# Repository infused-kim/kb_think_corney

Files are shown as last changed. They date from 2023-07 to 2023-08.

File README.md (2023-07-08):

# ThinkCorney

A wireless corne / crkbd ergonomic keyboard clone with support for a trackpoint. Built with ergogen v4.

> **Warning**
>
> This keyboard is still under development and not ready for manufacturing.

## Credits & Acknowledgements

- [Foostan's corne / crkbd](https://github.com/foostan/crkbd) for making the most popular ergo keyboard that is being used as the basis for this design
- Crehmann's [buzzard](https://github.com/crehmann/Buzzard) and [TPS42](https://github.com/crehmann/TPS42) for pioneering keyboards with trackpoints
- [Jon808517](https://reddit.com/r/ErgoMechKeyboards/comments/11ozztx/choc_spaced_corne_xiao/) for pointing me to the molex pico ezmate connector and joycon batteries
- And of course MrZealot for creating [ergogen](https://github.com/ergogen/ergogen)
- ceoloide for his awesome and creative ergogen tricks in [corney_island](https://github.com/ceoloide/corney-island/)

## License

**TLDR:**

- Personal use with attribution
- Commercial use not allowed

This work is licensed under a
[Creative Commons Attribution-ShareAlike 4.0 International License][cc-by-sa].

[][cc-by-sa]

[cc-by-sa]: http://creativecommons.org/licenses/by-sa/4.0/
[cc-by-sa-image]: https://licensebuttons.net/l/by-sa/4.0/88x31.png
[cc-by-sa-shield]: https://img.shields.io/badge/License-CC%20BY--SA%204.0-lightgrey.svg

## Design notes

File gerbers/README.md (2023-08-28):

# Gerbers for the ThinkCorney keyboard

Gerbers can be found in the [repo's releases section](../../../releases/).

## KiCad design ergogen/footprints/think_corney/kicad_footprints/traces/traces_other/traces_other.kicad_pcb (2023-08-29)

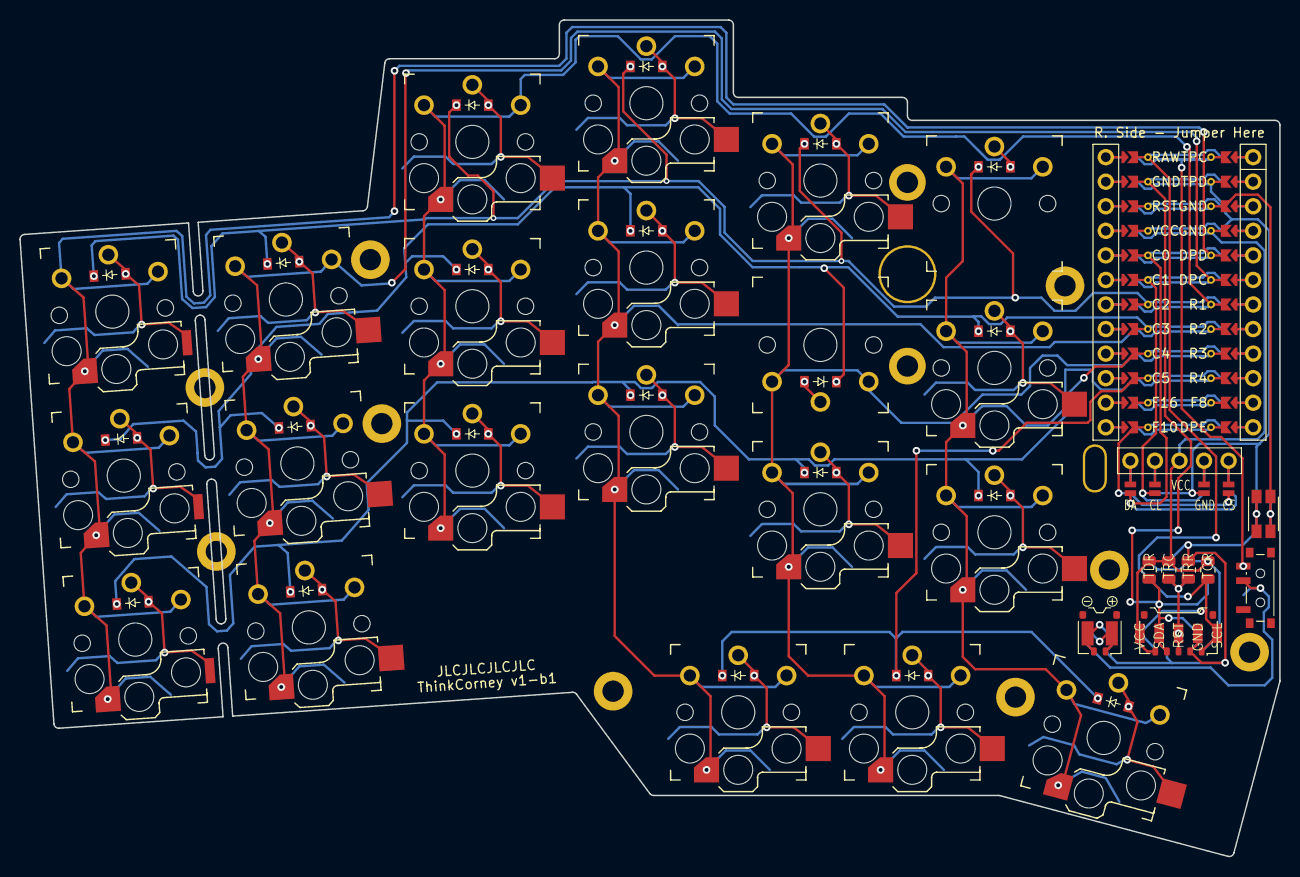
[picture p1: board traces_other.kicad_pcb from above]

Board: 2 copper layers, 130.3 x 86.5 mm, 112 parts (0 on the bottom side), 46 nets.

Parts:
CONN1: conn_molex_pico_ezmate_1x02
CONN2: conn_molex_pico_ezmate_1x05
D1, D2, D3, D4, D5, D6, D7, D8, D9, D10, D11, D12, D13, D14, D15, D16, D17, D18, D19, D20, D21: ComboDiode
DISP1: nice!view
H1, H2, H3, H4, H5, H6, H7, H8, H9, H10: mounting_hole
ICON1: icon_bat
MCU1: nice_nano
P1", P2", P3", P4", P5", P6", P7", P8", P9", P10", P11", P12", P13", P14", P15", P16", P17", P18", P19", P20", P21", P22", P23", P24", P25", P26", P27", P28", P29", P30", P31", P32", P33", P34", P35", P36", P37", P38", P39", P40", P41", P42", P43", P44", P45", P46", P47", P48", P49": point_debugger
PAD1, PAD2: pads
S1, S2, S3, S4, S5, S6, S7, S8, S9, S10, S11, S12, S13, S14, S15, S16, S17, S18, S19, S20, S21: PG1350
SMD1: smd_805
SW1: power_switch
SW2: sw_reset_side
TP1: trackpoint_mount_t430

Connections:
BAT_P: CONN1.1, PAD1.1, PAD1.2, SW1.2, SW1.5
C0: MCU1.5, S12.1, S13.1, S14.1
C1: MCU1.6, S15.1, S16.1, S17.1
C2: MCU1.7, S1.1, S2.1, S3.1
C3: MCU1.8, S4.1, S5.1, S6.1, S9.1
C4: MCU1.9, S7.1, S10.1, S18.1, S19.1
C5: MCU1.10, S8.1, S11.1, S20.1, S21.1
DISP1_1: DISP1.1, DISP1.14, DISP1.27
DISP1_2: DISP1.2, DISP1.15, DISP1.26
DISP1_4: DISP1.4, DISP1.16, DISP1.25
DISP1_5: DISP1.5, DISP1.17, DISP1.24
DPC: DISP1.11, DISP1.21, MCU1.119
DPD: DISP1.10, DISP1.20, MCU1.120
DPE: DISP1.13, DISP1.23, MCU1.113
GND: CONN1.2, CONN2.2, DISP1.12, DISP1.22, MCU1.2, MCU1.121, MCU1.122, PAD1.1, PAD1.2, PAD2.2, PAD2.4, SMD1.3, SMD1.5, SW2.1
R1: D3.1, D6.1, D9.1, D12.1, D18.1, D20.1, MCU1.118
R2: D2.1, D5.1, D8.1, D11.1, D19.1, D21.1, MCU1.117
R3: D1.1, D4.1, D7.1, D10.1, D13.1, D14.1, MCU1.116
R4: D15.1, D16.1, D17.1, MCU1.115
RAW: MCU1.1, SW1.3, SW1.6
RST: MCU1.3, SW2.2
TPC: CONN2.1, MCU1.124, PAD2.1, PAD2.5, SMD1.2, SMD1.8
TPD: CONN2.4, MCU1.123, PAD2.2, PAD2.4, SMD1.2, SMD1.8
TPR: CONN2.3, PAD2.3, SMD1.4, SMD1.6
VCC: CONN2.5, DISP1.3, MCU1.4, PAD2.1, PAD2.5, SMD1.1, SMD1.3, SMD1.5, SMD1.7
home_cluster: D16.2, S10.2
index_bottom: D13.2, S7.2
index_home: D19.2, S19.2
index_top: D18.2, S18.2
inner_bottom: D14.2, S8.2
inner_cluster: D17.2, S11.2
inner_home: D21.2, S21.2
inner_top: D20.2, S20.2
middle_bottom: D10.2, S4.2
middle_home: D11.2, S5.2
middle_top: D12.2, S6.2
outer_bottom: D1.2, S12.2
outer_cluster: D15.2, S9.2
outer_home: D2.2, S13.2
outer_top: D3.2, S14.2
pinky_bottom: D4.2, S15.2
pinky_home: D5.2, S16.2
pinky_top: D6.2, S17.2
ring_bottom: D7.2, S1.2
ring_home: D8.2, S2.2
ring_top: D9.2, S3.2

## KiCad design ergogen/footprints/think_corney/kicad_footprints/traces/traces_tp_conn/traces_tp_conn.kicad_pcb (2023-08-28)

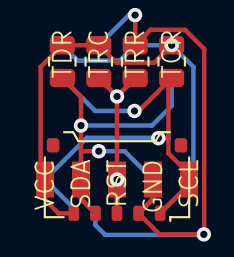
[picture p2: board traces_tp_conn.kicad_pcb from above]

Board: 2 copper layers, 5 parts (0 on the bottom side), 5 nets.

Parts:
CONN2: conn_molex_pico_ezmate_1x05
P40", P41": point_debugger
PAD2: pads
SMD1: smd_805

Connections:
GND: CONN2.2, PAD2.2, PAD2.4, SMD1.3, SMD1.5
TPC: CONN2.1, PAD2.1, PAD2.5, SMD1.2, SMD1.8
TPD: CONN2.4, PAD2.2, PAD2.4, SMD1.2, SMD1.8
TPR: CONN2.3, PAD2.3, SMD1.4, SMD1.6
VCC: CONN2.5, PAD2.1, PAD2.5, SMD1.1, SMD1.3, SMD1.5, SMD1.7

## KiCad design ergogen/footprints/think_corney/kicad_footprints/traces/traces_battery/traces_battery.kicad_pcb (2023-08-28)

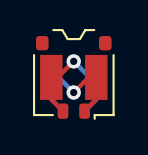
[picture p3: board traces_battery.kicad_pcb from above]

Board: 2 copper layers, 4 parts (0 on the bottom side), 2 nets.

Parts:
CONN1: conn_molex_pico_ezmate_1x02
P35", P36": point_debugger
PAD1: pads

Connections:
BAT_P: CONN1.1, PAD1.1, PAD1.2
GND: CONN1.2, PAD1.1, PAD1.2

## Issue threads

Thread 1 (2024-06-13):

Request for Build Guide/Bill of Parts or Alternative Build Resources

alikhatibak, 2024-06-13:
Request for Build Guide/Bill of Parts or Alternative Build Resources:

Firstly, I'd like to thank you, @infused-kim, for your incredible work on the zmk drivers for trackpoints, I'm very thankful for all you contributions and excited to get building myself!

I ordered your Think Corney PCB's from JLC PCB a while back and just got them yesterday, went ahead and put in switches and keycaps to get a feel for everything, and I'm super excited.

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

Despite this excitement, I am struggling to find resources for building your board, specifically when it comes to setting up the trackpoint module. I am assuming most of the other parts are pretty standard, diodes, nice!nano, nice!view, etc (although confirmation on that would be great) however sourcing everything and having a clear list to cross reference would be incredibly helpful.

If you are able to accommodate adding a Bill of Materials and/or a Build and Configuration Guide, it would be incredibly helpful and would be greatly appreciated by me, and possible others wanting to build their own Think Corney.

Thank you again for everything!

infused-kim, 2024-06-13:
Thank you so much for the praise and excitement.

I don’t have plans to create a build guide at the moment, because this is a very, very early design prototype that has quite a lot of flaws.

Building trackpoint keyboards is a bit of an unpaved road at the moment.

Primarily because many things haven’t been figured out yet.

I wouldn’t recommend it as a first build. If you have made keyboards before, then you should be able to figure it out.

You can find instructions on where to order trackpoints on the zmk discord in the #pointing-devices channel. I think it’s pinned.

You connect the TP using the ezmate pico connector. The 5-pin cables are a bit hard to source but you can find them on digikey and Ali express.

One of the biggest flaws of the design is that it requires you to solder tiny wires to the TP PCB. And it turns out the pads are very fragile. So be careful with that step.

That’s one of the many things I’ll change in a future redesign. But be mindful of it.

The ezmate pico PCB socket is also a pain in the ass to solder. But if you Google drag soldering you should find usable instructions.

The controller requires you to solder jumpers on the back of it. You can check the footprint source and search the ergogen discord discussions for more info on that type of controller connector.

Everything else is pretty standard. But I’m writing this from the top of my head.

Overall, I recommend double checking everything I said in the kicad file since it’s been a while since I designed it.

You can find a lot of info in the code and comments of the kicad footprints.

alikhatibak, 2024-06-14:
Thank you so much, this has been incredibly informative, and that answers most of my questions!

This isn't my first build, and i have a good bit of delicate soldering experience that should come in handy

Thank you again, take care

infused-kim, 2024-06-14:
You are welcome @alikhatibak. You can also consider ordering an FFC adapter board. That way you can connect the TP with the FPC cable instead of soldering it.

I haven't tried that yet, but that would be more reliable and less error-prone.

infused-kim, 2024-06-17:
One more thing I remembered just now. The power and reset switch is also totally different from most designs.

You can check the ergogen footprints for info on which models will work.

alikhatibak, 2024-06-18:
Thank you so much! I'll definitely consider the FCC board.

I'm struggling to find component names in the footprints, but did some digging and cross-referencing with parts on typeractive.xyz and landed on the `SSSS811101` Power Switch and the `EVQPUC02K` Reset Switch, how could I check if those components would work?

Not sure if I'm missing something, but on my end none of the components have comments/docs with part information, the most I've been able to get is footprint names like `sw_reset_side` and `power_ switch`. Some components have names like `conn_molex_pico_ezmate_1x05` where I can figure out the part from the name, but thats only been for the Molex Pico EZmate Connectors.

The config.yaml was helpful when it came to the SMD 0805 resistors and capacitors

```
# TP clock pull up resistor 4.7k
# TP Reset circuit resistor 100k
# TP Reset circuit capacitor 2.2uF
# TP data pull up resistor 4.7k
```

Is there any chance you have information on the following parts? Have I sourced the right ones? If not, could you point me in the right direction?

| Parts I'm Looking for | Part Numbers and Links |
|----|------|
|SMD Diodes| [1N4148W W1 SOD-123](https://www.aliexpress.us/item/3256803563930483.html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)
|Reset Switch| [EVQPUC02K](https://www.aliexpress.us/item/3256802779164165.html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)
|Power Switch| [SSSS811101](https://www.aliexpress.us/item/3256805469302826.html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)

Thank you again for your guidance through this build!

infused-kim, 2024-06-18:
You can find the actual footprints in this repo:
https://github.com/infused-kim/kb_ergogen_fp

The comments there have model numbers. The power switch from typeractive MIGHT fit, but the reset switch probably won't.

You can verify it by finding the datasheet with the pins and dimensions and compare it to the footprint in kicad.

The diodes should be fine.

I ordered most of my parts from digikey and just realized I have a list that should include most or all the parts:
https://www.digikey.com/en/mylists/list/2CGTLYAVKX

I _think_ these should all be correct, but I am not 100% certain and haven't verified it, especially the quantities of the parts.

alikhatibak, 2024-06-18:
Thank you so much, that's everything I think I need :) I was also unsure of whether to get the T460S or T440 TP, and the footprints in the linked repo helped me go with the T440.

infused-kim, 2024-06-19:
I don't have a good recommendation for which TP to use. So far all of them worked for me and I am currently using the red T460S one, because it has the smallest size.

One big downside of it is that it is quite fragile and you can easily pull the pads off it.

I am not sure about the T440 one. I also have a T430, which is much bulkier, but less fragile.

I have ordered a power consumption measuring device and will be able to give better recommendations in the future.

infused-kim, 2024-06-19:
And this is the reset switch I used:
https://www.digikey.com/en/products/detail/panasonic-electronic-components/EVQ-P7A01P/4429447

I just realized it wasn't on the list.

alikhatibak, 2024-06-19:
> I don't have a good recommendation for which TP to use. So far all of them worked for me and I am currently using the red T460S one, because it has the smallest size.
Is that the one in the Think Corney? I was worried it might not fit from some discussions in the zmk discord, I like the t460s if it works with the current PCB.

Thank you again, cant wait to get all the components.

Closed 2024-06-13.

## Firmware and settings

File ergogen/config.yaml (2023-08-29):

meta:
  engine: 4.0.4
  author: "@infused-kim"
  name: 'ThinkCorney'
  version: v1-b1
  full_name: &kb_full_name 'ThinkCorney v1-b1'

settings:
  preset:
    $extends: presets.kim
  point_debugger:
    enabled: true

presets:
  corne_choc:
    # Traces selector
    cfg_traces_matrix_profile: 1

    # Defaults
    cfg_diode_y: 3.8
    cfg_key_rotation: -180

    # Stagger
    cfg_stagger_outer: 0
    cfg_stagger_pinky: 0
    cfg_stagger_ring: 4.75
    cfg_stagger_middle: 2.375
    cfg_stagger_index: -2.375
    cfg_stagger_inner: -2.375

    # Splay
    cfg_splay_outer: 0
    cfg_splay_pinky: 0
    cfg_splay_ring: 0
    cfg_splay_middle: 0
    cfg_splay_index: 0
    cfg_splay_inner: 0
    cfg_splay_thumb_home: -15
    cfg_splay_thumb_inner: -15

    # Key Size
    cfg_kx: cx
    cfg_ky: cy
    cfg_kxo: 0.5 * cx
    cfg_kyo: 0.5 * cy
    cfg_keycaps_x: 17.5
    cfg_keycaps_y: 16.5

    # Adjustments for keys around trackpoint mount
    cfg_tp_key_index_top_hotswap: 1
    cfg_tp_key_index_top_rotation: cfg_key_rotation
    cfg_tp_key_index_top_rotation_trace: cfg_key_rotation
    cfg_tp_key_index_top_rotation_diode: 0
    cfg_tp_key_index_top_diode_y: cfg_diode_y
    cfg_tp_key_index_top_trace_variation: 0

    cfg_tp_key_index_home_hotswap: 0
    cfg_tp_key_index_home_rotation: cfg_key_rotation
    cfg_tp_key_index_home_rotation_trace: 0
    cfg_tp_key_index_home_rotation_diode: -180
    cfg_tp_key_index_home_diode_y: -1 * cfg_diode_y
    cfg_tp_key_index_home_trace_variation: 1

    cfg_tp_key_inner_top_hotswap: 0
    cfg_tp_key_inner_top_rotation: 0
    cfg_tp_key_inner_top_rotation_trace: cfg_key_rotation
    cfg_tp_key_inner_top_rotation_diode: 0
    cfg_tp_key_inner_top_diode_y: cfg_diode_y
    cfg_tp_key_inner_top_trace_variation: 1

    cfg_tp_key_inner_home_hotswap: 1
    cfg_tp_key_inner_home_rotation: cfg_key_rotation
    cfg_tp_key_inner_home_rotation_trace: cfg_key_rotation
    cfg_tp_key_inner_home_rotation_diode: 0
    cfg_tp_key_inner_home_diode_y: cfg_diode_y
    cfg_tp_key_inner_home_trace_variation: 0

    # Thumb Cluster offset from bottom index finger key
    cfg_thumb_cluster_offset_x: -8.5
    cfg_thumb_cluster_offset_y: -19.625

    # Distance adjustment of thumb key to align with rotation
    cfg_thumb_home_move_x:  2
    cfg_thumb_home_move_y: -2.7
    cfg_thumb_inner_move_x: 2.7
    cfg_thumb_inner_move_y: 2.3

    # Top & Bottom padding for outline
    cfg_pcb_outline_padding_top: 0.1
    cfg_pcb_outline_padding_left: 0
    cfg_pcb_outline_padding_right: 0

    # 1.5u rotated inner thumb settings
    cfg_splay_thumb_inner_extra: 90
    cfg_keycaps_thumb_inner_x: 26.5
    cfg_keycaps_thumb_inner_y: 16.5
    cfg_thumb_inner_width: 1.5
    cfg_edge_thumb_cluster_top_shift_x: cfg_thumb_inner_width * 0.5 * cfg_kx
    cfg_edge_thumb_cluster_top_shift_y: -0.5 * cfg_ky
    cfg_edge_thumb_cluster_bottom_shift_x: -0.5 * cfg_kx * cfg_thumb_inner_width - cfg_pcb_outline_padding_top
    cfg_edge_thumb_cluster_bottom_shift_y: 0

    # Mounting Holes
    cfg_mounting_hole_thumb_inner_shift_y: 1.5
    cfg_mounting_hole_pinky_shift_y: 0

    # Breakoff Column Cuts
    cfg_breakoff_coulmn_inner_y: 7.5
    cfg_breakoff_column_outer_y: 7.5

  corne_choc_mx_spacing:
    $extends: presets.corne_choc

    # Traces selector
    cfg_traces_matrix_profile: 2

    # Key size
    cfg_kx: u
    cfg_ky: u

    # Thumb Cluster offset from bottom index finger key
    cfg_thumb_cluster_offset_x: -9.5

    # Distance adjustment of inner thumb key
    cfg_thumb_inner_move_x: 3.504
    cfg_thumb_inner_move_y: 2.07

    # Top & Bottom padding for outline
    cfg_pcb_outline_padding_top: -0.35
    cfg_pcb_outline_padding_left: -0.5

    # Breakoff Column Cuts
    cfg_breakoff_column_outer_y: 8.5
    cfg_breakoff_coulmn_inner_y: 8.5

  chocofi:
    $extends: presets.corne_choc

    # Traces selector
    cfg_traces_matrix_profile: 3

    # Stagger
    cfg_stagger_ring: 12
    cfg_stagger_middle: 6
    cfg_stagger_index: -6.62
    cfg_stagger_inner: -2.38

    # Thumb Cluster offset from bottom index finger key
    cfg_thumb_cluster_offset_x: -6
    cfg_thumb_cluster_offset_y: -20

    # Spacing required for outline to get a straight edge for the inner side
    cfg_thumb_edge_offset: 0
    cfg_pcb_outline_padding_right: 1.2

  kim:
    $extends: presets.corne_choc

    # Traces selector
    cfg_traces_matrix_profile: 4

    # Stagger
    cfg_stagger_ring: 15
    cfg_stagger_middle: 4
    cfg_stagger_index: -8
    cfg_stagger_inner: -2.38

    # Splay
    cfg_splay_outer: 4
    cfg_splay_pinky: 0
    cfg_splay_ring: -4
    cfg_splay_middle: 0
    cfg_splay_index: 0
    cfg_splay_inner: 0
    cfg_splay_thumb_home: 0
    cfg_splay_thumb_inner: -15

    # Thumb Cluster offset from bottom index finger key
    cfg_thumb_cluster_offset_x: -8.5
    cfg_thumb_cluster_offset_y: -21
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

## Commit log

2023-04-16 Added initial (wrong) corne outline
    [config.yaml]
2023-04-16 Added initial pcb design
    Space out PCB section
2023-04-16 PCB: Added reversible promicro_pretty footprint
2023-04-16 Rotate switches to be in the same orientation as most split keyboards
2023-04-17 Added original erogegen v4 choc footprint
2023-04-17 Choc Footprint: Added corner marks to silkmask
2023-04-17 Choc Footprint: Added hotswap outline
2023-04-18 Makefile: Added backups and restoring of traces
2023-04-22 Added nice!view footprint (not dynamic)
2023-04-22 Choc Footprint: Add option to show 1.5u keycap outline
2023-04-22 Ergogen: Switch oled to reversible nice!view footprint
2023-04-24 Power Switch FP: Added initial design
2023-04-24 Ergogen: Added power switch
2023-04-24 Bat Conn FP: Added
    Fixed battery connector
2023-04-24 Ergogen: Added battery connector
    Ergogen: Rotated battery connector
2023-04-24 Ergogen: Added trackpoint connector
2023-04-24 Battery Icon FP: Added
2023-04-24 Ergogen: Added battery icon
2023-04-24 Ergogen: Added pads for battery and trackpoint
2023-04-25 Switch Reset: Added
2023-04-25 Ergogen: Added reset switch
2023-04-25 Pro Micro FP: Added labels
    [think_corney_orig.kicad_pcb]
2023-04-25 Ergogen: Added pin labels
2023-04-26 Ergogen: Assign descriptive nets to pro micro pins
    Fix thumb columns
    [config.yaml]
2023-04-26 Ergogen: Adjust MCU vertical location based on correct size
    [config.yaml]
2023-04-26 Ergogen: Position display correctly
    Remove old display
    [config.yaml]
2023-04-26 Ergogen: Switched trackpoint to use high frequency pins
2023-04-27 Power Switch FP: Renamed power_switch -> switch_power
2023-04-27 Ergogen: Fix incorrect thumb keycap size and position
    [config.yaml]
2023-04-27 Trackpoint Mount FP: Added with T430 outline
2023-04-27 Ergogen: Added trackpoint mount
2023-04-27 Diode FP: Added ergogen original
2023-04-27 Diode FP: Added option to disable throughhole diode
2023-04-28 Choc FP: Added option to show both hotswap and through-hole at once
2023-04-28 Ergogen: Flip trackpoint switches and add non-hotswap soldering option
    [config.yaml]
2023-04-28 Trackpoint Mount FP: Added estimated outline for x240
2023-04-28 Ergogen: Remove old reset switch
2023-04-30 Ergogen: Add trackpoint reset circuit
    [config.yaml]
2023-04-30 Makefile: Only copy kicad PCB and not all output files
    If you opened the project in the output fodler, copying everything overwrote the production non-pcb files.
2023-04-30 PCB: Add generated pcb version
    [think_corney.kicad_pcb, think_corney_orig.kicad_pcb]
2023-04-30 Kicad: Added JLCPCB design rules
    [think_corney.kicad_pcb]
2023-04-30 KiCad: Added track widths for regular and power lines
2023-04-30 All Footprints: Set footprint type to remove DRC error
    Change virtual to smd attr
2023-04-30 Choc FP: Made hotswap pads not overlap holes to fix DRC error
2023-04-30 Choc FP: Fix DRC warning “Drilled holes co-located” for hotswap socket
2023-04-30 Choc FP: Fix DRC warning “Drilled holes co-located” for thru hole variant
2023-04-30 Power Switch: FP: Fix DRC warning “Drilled holes co-located”
2023-04-30 Reset Switch FP: Remove silkscreen outline of button to silence DRC warning
2023-04-30 Switch Reset FP: Fix designator and ref
2023-04-30 KiCad: Fix many DRC problems
    [think_corney.kicad_pcb, think_corney_orig.kicad_pcb]
2023-05-04 Nice Nano FP: Added all dynamic elements and traces
2023-05-05 Ergogen: Switch to new nice!nano footprint
2023-05-05 Nice Nano FP: Remove logs and remove trace nets
2023-05-05 Ergogen: Move outline section below pcb section
2023-05-05 Ergogen: Move controller to top of pcb section
2023-05-05 Makefile: Add build-nt target that doesn’t restore traces
2023-05-05 Text FP: Add text directly to PCB and not through a footprint
2023-05-05 Ergogen: Increase left side outline to fix DRC errors due to cut off pad
    [config.yaml]
2023-05-05 Kicad: Untrack think_corney_orig.kicad_pcb
    [think_corney_orig.kicad_pcb]
2023-05-06 Footprints: Moved all footprints to separate repo
2023-05-06 Footprints: Updated to latest version
2023-05-06 KiCad: Adjusted DRC warning levels and net defaults
2023-05-06 KiCad: Updated PCB to latest ergogen generated version
    [think_corney.kicad_pcb]
2023-05-06 Makefile: Various improvements including locking of traces generated in ergogen
2023-07-08 Ergogen: Switch back to choc config
2023-07-09 Ergogen: Reduce corner radius of board outline
2023-07-16 Ergogen: Added cutout for battery wires
2023-07-18 Ergogen: Added mounting holes
2023-07-18 Ergogen: Updated mounting holes for new to support oval hole parameters
2023-07-18 Ergogen: Added oval hole to put battery connector through
2023-07-18 Ergogen: Removed battery wire cutout on the right side
2023-07-18 Ergogen: Added display cover holes
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2023-07-18 Ergogen: Change trackpoint connector pin order to red trackpoint
2023-07-19 Footprints: Use nice!nano fp that has more space for traces
2023-07-19 PCB: Update to latest pcb version with initial traces
    [think_corney.kicad_pcb]
2023-07-19 Git: Ignore svg files in pcb dir
    [think_corney.kicad_pcb]
2023-07-19 Ergogen: Allow presets to unflip keys
    Ergogen: Move diode up for flipped keys
    [config.yaml]
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2023-08-26 Footprints: Added traces_key footprint kicad file
    Ignore kicad_pro for traces kicad files
    [traces_key.kicad_pcb]
2023-08-26 Key Traces: Fix too long traces when using smaller hotswap pads
    [traces_key.kicad_pcb]
2023-08-27 Traces: Added initial matrix traces
    [think_corney.kicad_pcb, traces_matrix.kicad_pcb]
2023-08-27 Ergogen: Made matrix traces selectable based on profile
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2023-08-27 Ergogen: Added ability to customize keys around TP mount individually
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2023-08-28 Footprints: Moved traces pcb files to subfolders
    [traces_key.kicad_pcb, traces_matrix.kicad_pcb]
2023-08-28 Traces: Fixed matrix traces for TP key changes
    Added pcb
    [think_corney.kicad_pcb, traces_matrix.kicad_pcb]
2023-08-28 Traces: Added traces for batter conn + pad
    [think_corney.kicad_pcb, traces_battery.kicad_pcb]
2023-08-28 Traces: Added trackpoint conn traces
    [think_corney.kicad_pcb, traces_tp_conn.kicad_pcb]
2023-08-28 Traces: Added display traces
    [think_corney.kicad_pcb, traces_display.kicad_pcb]
2023-08-28 Traces: Added other traces
    [think_corney.kicad_pcb, traces_other.kicad_pcb]
2023-08-28 Traces: Added remaining missing traces
    [think_corney.kicad_pcb, traces_display.kicad_pcb, traces_matrix.kicad_pcb]
2023-08-28 Traces: Fix potential DRC clearance errors in battery footprint
    [traces_battery.kicad_pcb]
2023-08-28 Traces: Fix potential DRC clearance errors in TP conn footprint
    [traces_other.kicad_pcb, traces_tp_conn.kicad_pcb]
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2023-08-28 PCB: Submitted test to jlcpcb
    [think_corney.kicad_pcb]
2023-08-29 Ergogen: Decreased mounting hole sizes to 2.2mm
    [think_corney.kicad_pcb]
2023-08-29 Ergogen: Increase battery hole size
    [think_corney.kicad_pcb]
2023-08-29 Ergogen: Moved reset switch closer to board edge
    [think_corney.kicad_pcb, traces_other.kicad_pcb]
